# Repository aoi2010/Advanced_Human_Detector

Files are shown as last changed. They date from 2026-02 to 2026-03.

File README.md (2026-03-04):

# Advanced Human Detector
This is a human detector which uses HmmD Mmwave Sensor to detect humans.

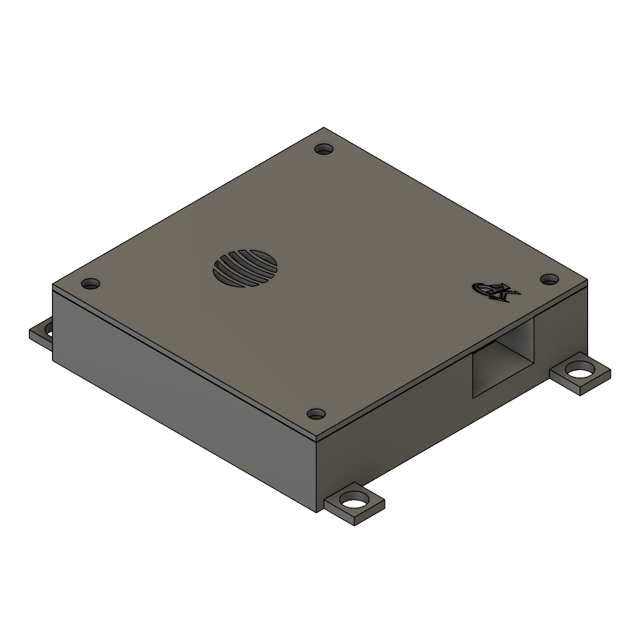
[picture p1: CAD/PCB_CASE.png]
PCB Case


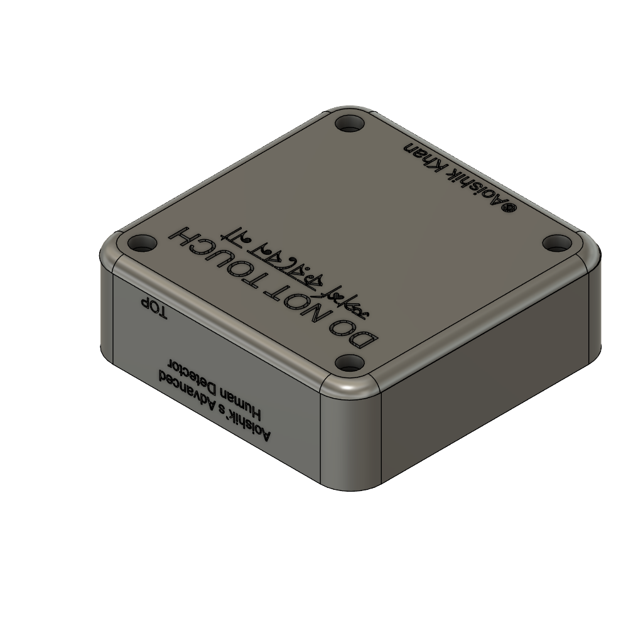
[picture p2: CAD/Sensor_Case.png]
Sensor Case


### Inspiration

I wanted to create a human detector using the Mmwave Sensor to detect humans and alert me when human is detected cuz some people always steals the flowers in my garden, and I want to catch them in the act.

### Challenges

Believe it or not, this was my second time using Fusion 360 and KiCad! I watched numerous tutorials and guides and did a kg of googling, but in the end, I'm pretty proud of the final product. I had the most struggle figuring out how to make sketches, and with the new mouse controls, it definitely took me a while to get the hang of it. Also in KiCad, I had a lot of trouble with footprints and making sure everything was aligned properly and the traces were correct(but it became a litle long traces).

### How To Use This
- STEP 1: Buy all the things listed in the BOM, a 0.1µf decoupling capacitor(ceramic & and not mentioned in BOM) & print the case for the sensor and also order the PCB(PCB/motionalr_mcu.zip).
- STEP 2: Solder the 0.1µf decoupling capacitor to the HMMD mmWave Sensor. One leg of it to VCC and another leg to GND.
- STEP 3: Assemble the PCB.
- STEP 4: Flash MicroPython to the XIAO and place the main.py in the XIAO.
- STEP 5: Connect the PCB to the sensor using a LAN Cable(less than 3m) or any twisted Pair Cable(Use the following table as reference).

| Twisted Pair | Use For |
| --- | --- |
| Pair 1 | 3.3V + GND |
| Pair 2 | TX + GND |
| Pair 3 | RX + GND |
| Pair 4 | OT2 + GND |

- STEP 6: Put the sensor in the case and put it outside or where you want it to be placed.(You may put it near your bedroom so that it alerts you when someone is coming or near your fridge if you have siblings.)
- STEP 7: Put the PCB inside your house while connected to the sensor using a lan cable(length must be less than 3m).
- STEP 8: Power the XIAO using a USB-C Cable.
- STEP 9: Sleep peacefully or If you want to test go near it and see how it screams.
- STEP 10: Do Anything With It.
Thank You! Also Please give a star to this poor fellow if you like the project. Thank You Again!

### Specifications

BOM: 
- 1x [Seeed Studio XIAO ESP32-C3 development board](https://robu.in/product/seeed-studio-xiao-esp32c3-tiny-mcu-board-with-wi-fi-and-ble-battery-charge-supported-power-efficiency-and-rich-interface/)
- 1x [Waveshare HMMD 24 GHz mmWave human presence sensor](https://robu.in/product/waveshare-human-micro-motion-detection-mmwave-sensor-24ghz-mmwave-radar-based-on-s3km1110-adopts-fmcw-technology/)
- 1x [Passive piezo buzzer, 3 V, Ø12 mm](https://robu.in/product/hc12075c-16-cldz-electromagnetic-passive-integrated-buzzer-1-5-3v12x7-5mmimpedance16%CF%89lateralpronunciation/)
- 1x [NPN transistor 2N2222, TO-92 package](https://robu.in/product/2n2222-npn-transistor-pack-of-20/)
- 1x [Resistor 10 kΩ, ¼ W, through-hole](https://robu.in/product/mfr-25frf52-10k-yageo-metal-film-resistors-10k%CF%89-250mw-%C2%B1100ppm-%E2%84%83-%C2%B11-plugind2-4xl6-3mm-through-hole-resistors-rohs/)
- 1x [Resistor 1 kΩ, ¼ W, through-hole](https://robu.in/product/1k-ohm-0-25w-metal-film-resistor-pack-of-100/)
- 1x [Resistor 100–200 Ω, ¼ W, through-hole](https://robu.in/product/0-25w-100-ohm-resistor-pack-of-100/)
- 1x [Resistor 22–33 Ω, through-hole](https://robu.in/product/mf25-33r-multicomp-pro-through-hole-resistor-33-ohm-mf25-series-250-mw-%C2%B1-1-axial-leaded-250-v)
- 1x [Signal diode 1N4148](https://robu.in/product/1n4148-onsemi-100v-1v10ma-4ns-200ma-do-35-switching-diodes-rohs/)
- 2x [0 Ω SMD resistor](https://robu.in/product/1-month-warranty-149/)
- 1x [5-pin connector / header for HMMD sensor - Male](https://robu.in/product/xh-a-2-5mm-5-pin-wafer-male-connector-through-hole-straight/)
- 1x [5-pin connector / header for HMMD sensor - Female](https://robu.in/product/xh-a-aw-2-5mm-5-pin-female-housing-connector-with-300mm-wire28-awg/)
- 1x [LAN / multi-core cable for sensor connection](https://www.amazon.in/Electronic-Spices-Ethernet-Patch-Network/dp/B0D4HYL67Z)
- 4x [M3x16mm Screws](https://onlyscrews.in/products/copy-of-chhd-m3-x-20mm-pack-of-21?variant=48458789257529)
- 4x [M3x4mm Heatset Inserts](https://onlyscrews.in/products/m4-x-4mm-brass-threaded-inserts?variant=49091565650233)
- 1x [PCB](https://www.lioncircuits.com/) 

Others:
- Micropython Firmware
- PCB Gerber File(PCB/motionalr_mcu.zip)
- Case STL files for 3d Printing
- BOM.csv

Schematic            |  PCB         |   Sensor Case (Top)   |   Sensor Case (Bottom)
:-------------------------:|:-------------------------:|:-------------------------:|:-------------------------:|
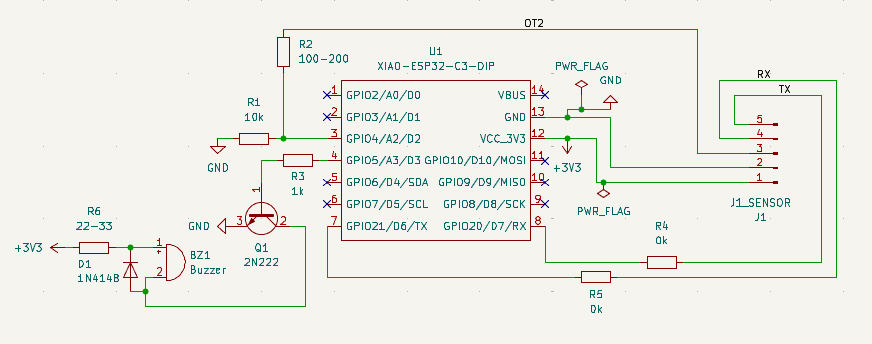
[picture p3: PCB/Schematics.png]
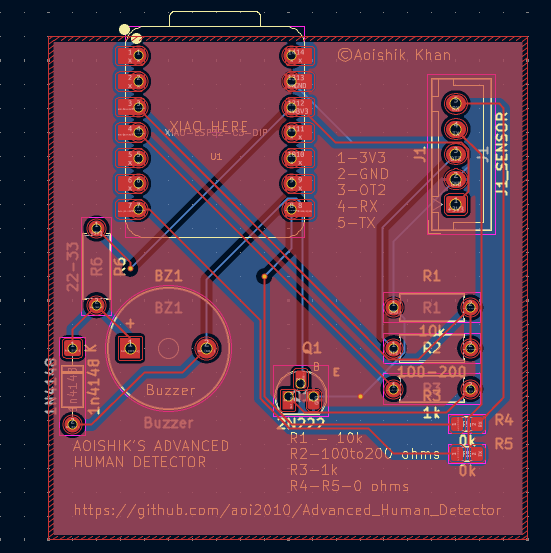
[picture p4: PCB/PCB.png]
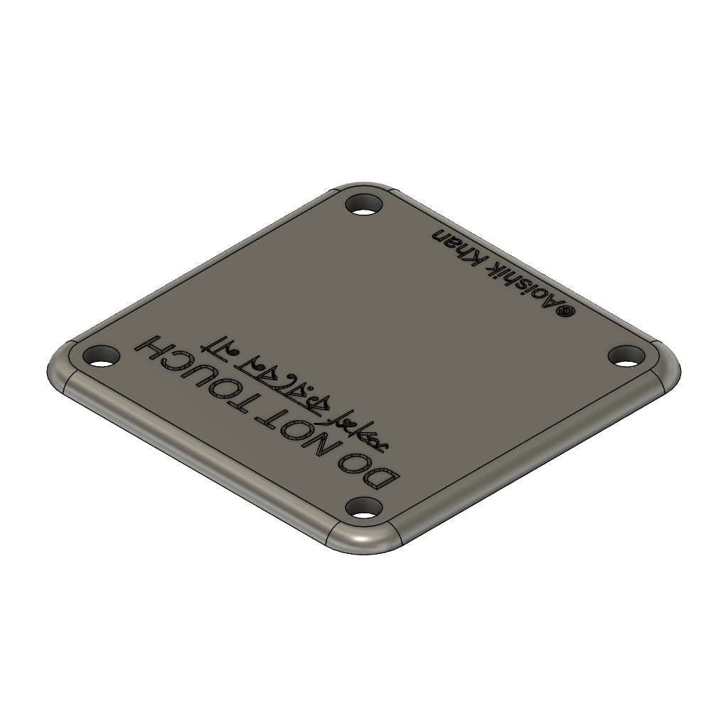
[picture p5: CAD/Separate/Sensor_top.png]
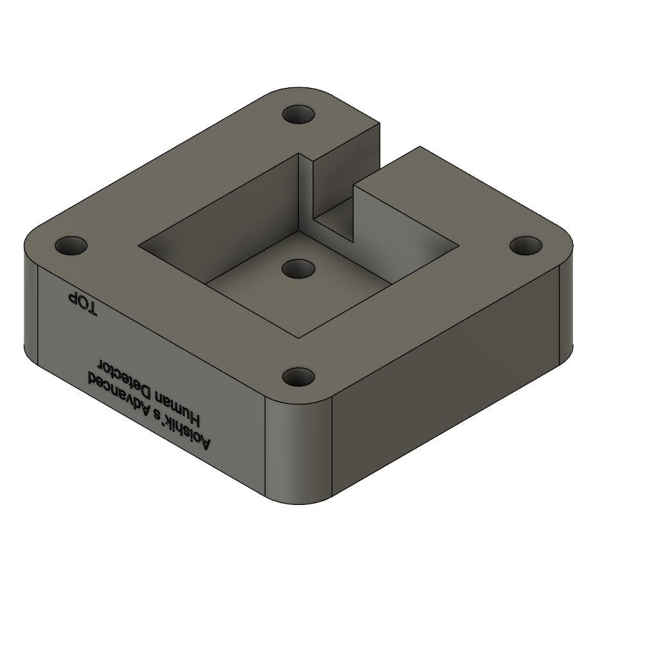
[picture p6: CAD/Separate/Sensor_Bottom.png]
    |    |  | 

PCB Case (Top)            |  PCB Case (Bottom)
:-------------------------:|:-------------------------:
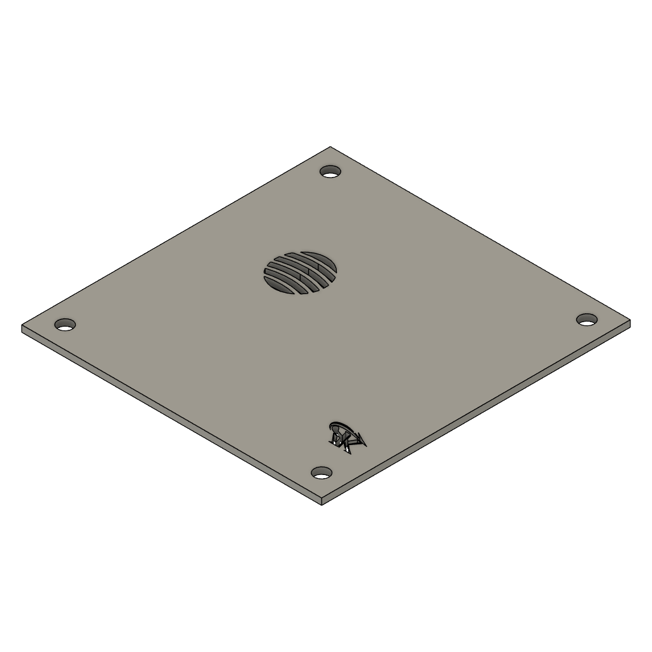
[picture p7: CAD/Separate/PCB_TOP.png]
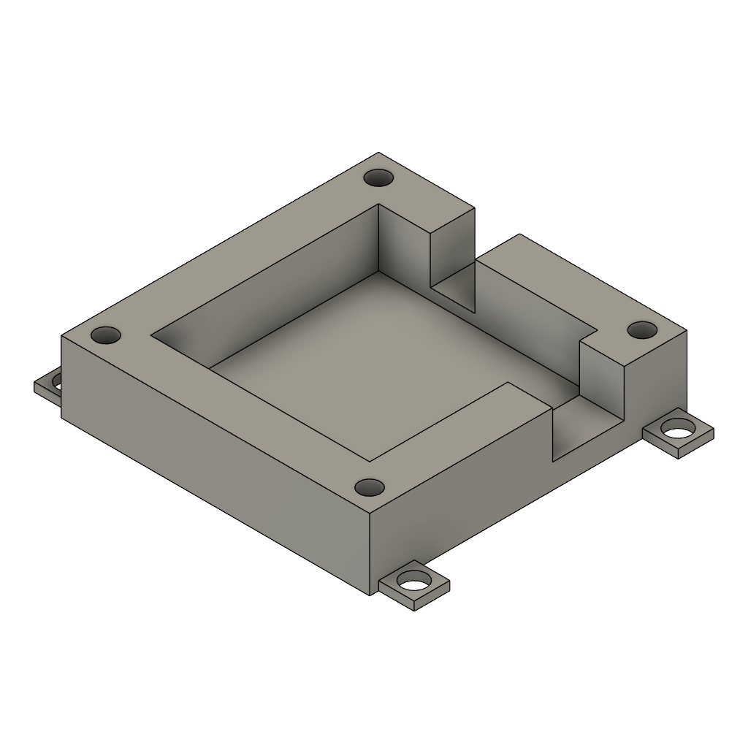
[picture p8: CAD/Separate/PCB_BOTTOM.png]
    |  

### Notes
The code is still basic in functionality because of lack of information on the sensor datasheet, but I will update it as soon as I get the sensor and debug it's output. The case for the mmwave sensor is measured with approx measurement available online, so I will also update the case design once I get the sensor and measure it myself. The PCB will be left bare as I like looking at PCBs.

Edit: I also made the PCB case but after my project was approved. Thank You for understanding.
<div align="center">

## Thanks For Reading! Also leave a star if you like the project! ⭐

</div>

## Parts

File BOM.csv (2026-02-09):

Item | Description | Quantity | Unit Price Approx($) | Unit Price(INR) | Total Price Approx ($) | Total Price(INR) | URL | Product Name in Product Page | Notes
XIAO-ESP32-C3 | Seeed Studio XIAO ESP32-C3 development board | 1 | 5.93 | 534 | 5.93 | 534 | https://robu.in/product/seeed-studio-xiao-esp32c3-tiny-mcu-board-with-wi-fi-and-ble-battery-charge-supported-power-efficiency-and-rich-interface/ | Seeed Studio XIAO ESP32C3 – tiny MCU board with Wi-Fi and BLE
HMMD-mmWave Sensor | HMMD 24 GHz mmWave human presence sensor | 1 | 3.37 | 303 | 3.37 | 303 | https://robu.in/product/waveshare-human-micro-motion-detection-mmwave-sensor-24ghz-mmwave-radar-based-on-s3km1110-adopts-fmcw-technology/ | Waveshare Human Micro-Motion Detection mmWave Sensor, 24GHz mmWave Radar, Based On S3KM1110, Adopts FMCW Technology
BUZZER-PASSIVE | Passive piezo buzzer, 3 V, Ø12 mm | 1 | 0.13 | 12 | 0.13 | 12 | https://robu.in/product/hc12075c-16-cldz-electromagnetic-passive-integrated-buzzer-1-5-3v12x7-5mmimpedance16%CF%89lateralpronunciation/ | HC12075C-16-CLDZ-Electromagnetic passive integrated buzzer-1.5-3V (12×7.5mm) Impedance 16ΩLateral pronunciation
Transistor-2N2222 | NPN transistor 2N2222, TO-92 package | 1 | 0.02 | 2 | 0.02 | 2 | https://robu.in/product/2n2222-npn-transistor-pack-of-20/ | 2N2222 NPN Transistor
Resistor-10K Ω | Resistor 10 kΩ, ¼ W, through-hole | 1 | 0.02 | 1.91 | 0.02 | 1.91 | https://robu.in/product/mfr-25frf52-10k-yageo-metal-film-resistors-10k%CF%89-250mw-%C2%B1100ppm-%E2%84%83-%C2%B11-plugind2-4xl6-3mm-through-hole-resistors-rohs/ | MFR-25FRF52-10K-YAGEO-Metal Film Resistors 10kΩ 250mW ±100ppm/℃ ±1% Plugin,D2.4xL6.3mm Through Hole Resistors ROHS
Resistor-1K Ω | Resistor 1 kΩ, ¼ W, through-hole | 1 | 0.1 | 0.35 | 0.1 | 0.35 | https://robu.in/product/1k-ohm-0-25w-metal-film-resistor-pack-of-100/ | 1k Ohm 0.25W Metal Film Resistor
Resistor-100–200 Ω | Resistor 100–200 Ω, ¼ W, through-hole | 1 | 0.1 | 0.29 | 0.1 | 0.29 | https://robu.in/product/0-25w-100-ohm-resistor-pack-of-100/ | 100 Ohm 0.25W Metal Film Resistor
Resistor-22–33Ω | Resistor 22–33 Ω, through-hole | 1 | 0.02 | 2.08 | 0.02 | 2.08 | https://robu.in/product/mf25-33r-multicomp-pro-through-hole-resistor-33-ohm-mf25-series-250-mw-%C2%B1-1-axial-leaded-250-v | MF25 33R-MULTICOMP PRO-Through Hole Resistor, 33 ohm, MF25 Series, 250 mW, ± 1%, Axial Leaded, 250 V
Diode-1N4148 | Signal diode 1N4148 | 1 | 0.07 | 6 | 0.07 | 6 | https://robu.in/product/1n4148-onsemi-100v-1v10ma-4ns-200ma-do-35-switching-diodes-rohs/ | 1N4148-Onsemi-100V 1V@10mA 4ns 200mA DO-35 Switching Diodes ROHS
Resistor-0R | 0 Ω SMD resistor | 2 | 0.05 | 0.16 | 0.1 | 0.32 | https://robu.in/product/1-month-warranty-149/ | RC0805FR-070RL-YAGEO-0 Ohms Jumper Chip Resistor 0805 (2012 Metric) Moisture Resistant Thick Film
5pin Connector-Male | 5-pin connector / header for HMMD sensor - Male | 1 | 0.01 | 1.26 | 0.01 | 1.26 | https://robu.in/product/xh-a-2-5mm-5-pin-wafer-male-connector-through-hole-straight/ | XH-A-2.5mm-5 pin Wafer Male Connector Through Hole Straight
5pin Connector-Female | 5-pin connector / header for HMMD sensor - Female | 1 | 0.14 | 13 | 0.14 | 13 | https://robu.in/product/xh-a-aw-2-5mm-5-pin-female-housing-connector-with-300mm-wire28-awg/ | XH-A/AW-2.5mm-5 pin Female Housing Connector with 300mm Wire(28 AWG)
LAN CABLE | LAN / multi-core cable for sensor connection | 1 | 1.88 | 169 | 1.88 | 169 | https://www.amazon.in/Electronic-Spices-Ethernet-Patch-Network/dp/B0D4HYL67Z | Electronic Spices RJ45 Cat 6 Cable Ethernet Patch LAN Network Laptop Cable (2 M),2M, Grey
Screws | M3x16mm Screws | 4 | 0.02 | 2.12 | 0.08 | 8.48 | https://onlyscrews.in/products/copy-of-chhd-m3-x-20mm-pack-of-21?variant=48458789257529 | M3 X 16mm Slotted CHHD SS 304 Screw (Dia. 3mm, Length 16mm)
Heat Set Inserts | M3x4mm Heatset Inserts | 4 | 0.03 | 2.6 | 0.12 | 10.4 | https://onlyscrews.in/products/m4-x-4mm-brass-threaded-inserts?variant=49091565650233 | M3 X 4mm Brass Threaded Inserts (Dia. 3mm, Length 4mm)
ONLYSCREWS SHIPPING | Shipping Charges | 1 | 0.67 | 60 | 0.67 | 60 | N/A | N/A
Robu Shipping | Shipping Charges | 1 | 0.54 | 49 | 0.54 | 49 | https://support.robu.in/index.php | N/A | My Order is Not Above Rs. 999
PCB | PCB Fabrication | 5 | 2.15 | 193.2 | 10.73 | 966 | https://www.lioncircuits.com/ | PCB Fabrication - Lion Circuits | Lion Circuits

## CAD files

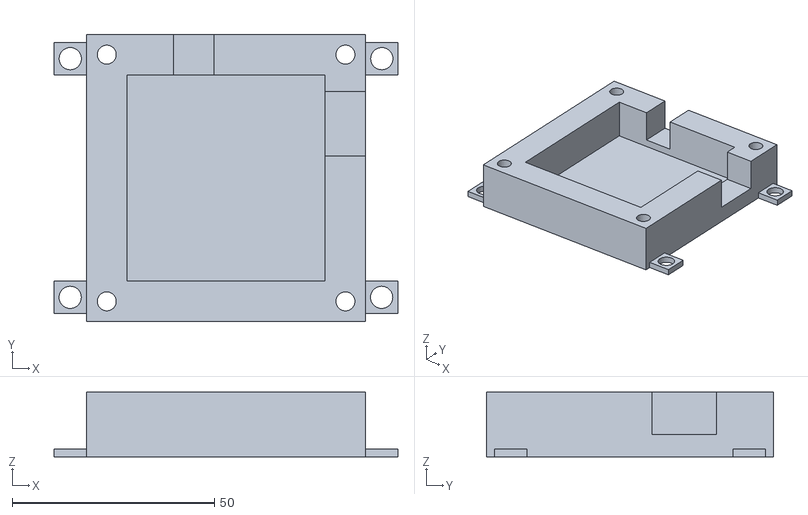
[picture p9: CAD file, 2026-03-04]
CAD/For 3d Printing/PCB_Bottom.stl
85.0 x 71.0 x 16.0

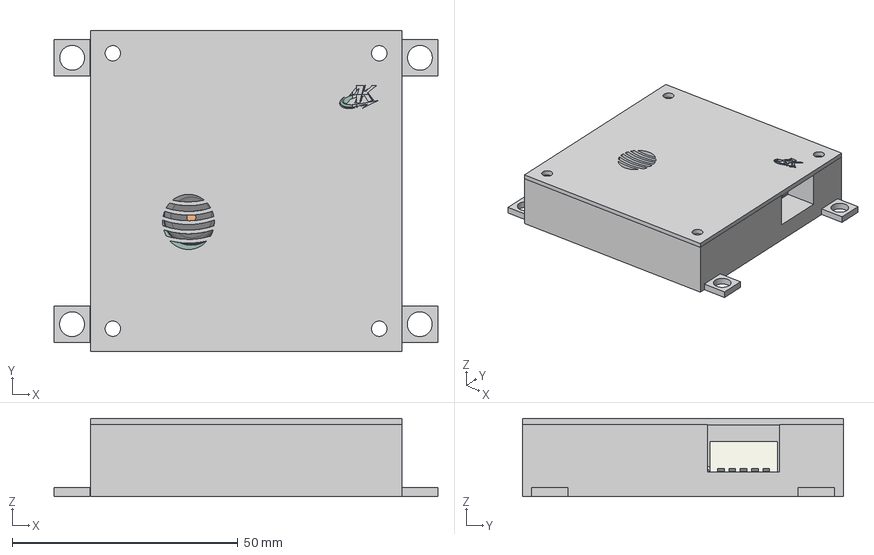
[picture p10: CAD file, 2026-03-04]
CAD/PCB_Case.step
85.0 x 71.0 x 17.4 mm

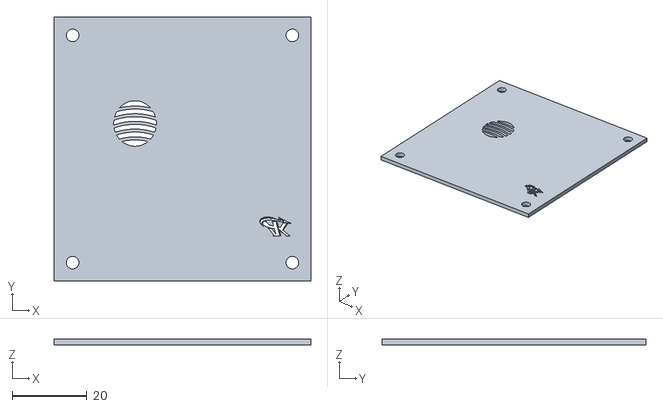
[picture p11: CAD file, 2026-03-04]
CAD/For 3d Printing/PCB_TOP.stl
69.0 x 71.0 x 1.50

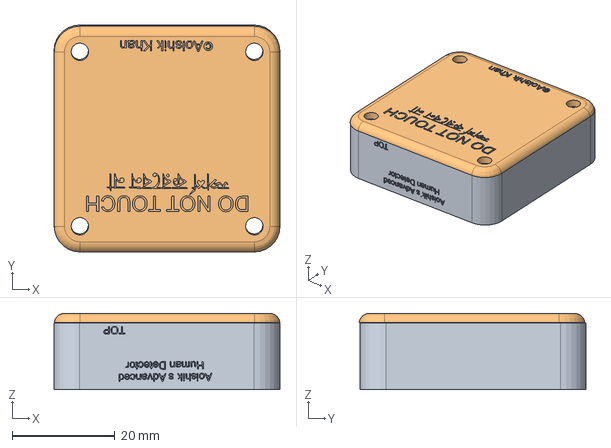
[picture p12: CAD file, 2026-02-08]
CAD/Sensor_Case.step
44.0 x 44.2 x 14.8 mm

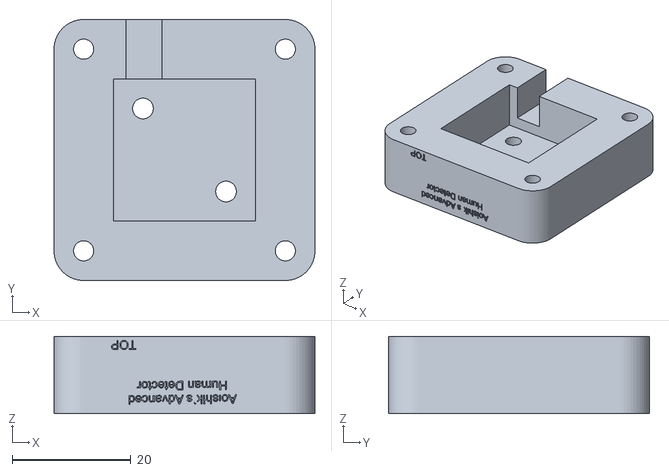
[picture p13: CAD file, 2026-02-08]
CAD/For 3d Printing/Sensor_Bottom.stl
44.0 x 44.0 x 13.0

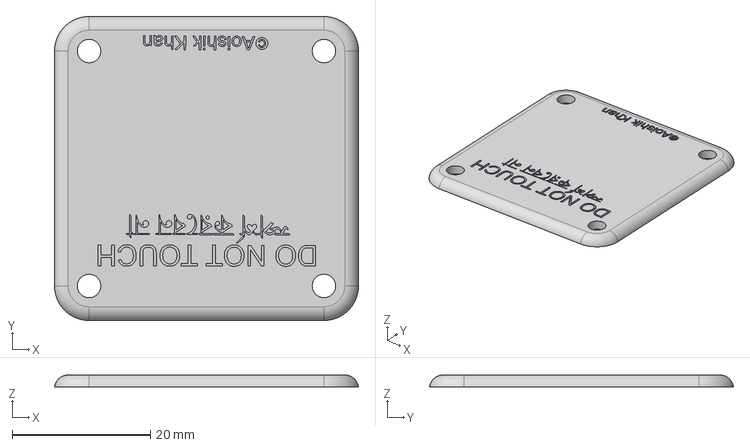
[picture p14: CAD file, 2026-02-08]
CAD/Separate/Sensor_top.step
44.0 x 44.0 x 1.75 mm

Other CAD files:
CAD/Separate/PCB_BOTTOM.step
CAD/Separate/PCB_TOP.step
CAD/For 3d Printing/Sensor_top.stl
CAD/Separate/Sensor_Bottom.step
CAD/PCB_Case.f3z
CAD/Sensor_Case.f3z
CAD/Separate/Sensor_Bottom.f3d
CAD/Separate/Sensor_Top.f3d

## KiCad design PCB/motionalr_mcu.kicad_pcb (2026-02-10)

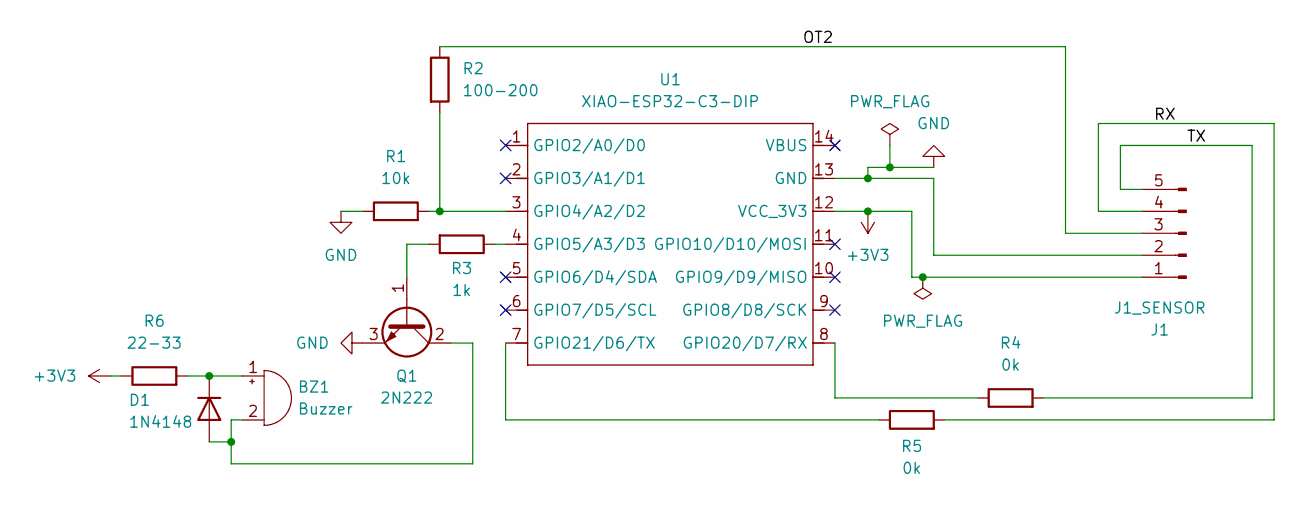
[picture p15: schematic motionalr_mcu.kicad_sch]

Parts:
BZ1: Buzzer; Buzzer_12x9.5RM7.6
D1: 1N4148; D_DO-35_SOD27_P7.62mm_Horizontal
J1: J1_SENSOR; JST_XH_B5B-XH-A_1x05_P2.50mm_Vertical
Q1: 2N222; TO-92_HandSolder
R1: 10k; R_Axial_DIN0207_L6.3mm_D2.5mm_P7.62mm_Horizontal
R2: 100-200; R_Axial_DIN0207_L6.3mm_D2.5mm_P7.62mm_Horizontal
R3: 1k; R_Axial_DIN0207_L6.3mm_D2.5mm_P7.62mm_Horizontal
R4, R5: 0k; R_0805_2012Metric_Pad1.20x1.40mm_HandSolder
R6: 22-33; R_Axial_DIN0207_L6.3mm_D2.5mm_P7.62mm_Horizontal
U1: XIAO-ESP32-C3-DIP; XIAO-ESP32C3-DIP

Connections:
+3V3: J1.1, R6.1, U1.12 (VCC_3V3)
/OT2: J1.3, R2.1
/RX: J1.5, R4.2
/TX: J1.4, R5.2
GND: J1.2, Q1.3 (E), R1.1, U1.13 (GND)
unnamed 5: BZ1.1 (+), D1.1 (K), R6.2; also elsewhere on the board
unnamed 6: BZ1.2 (-), D1.2 (A), Q1.2 (C); also elsewhere on the board
unnamed: Q1.1 (B), R3.2
unnamed: R1.2, R2.2, U1.3 (GPIO4/A2/D2)
unnamed: R3.1, U1.4 (GPIO5/A3/D3)
unnamed: R4.1, U1.8 (GPIO20/D7/RX)
unnamed: R5.1, U1.7 (GPIO21/D6/TX)

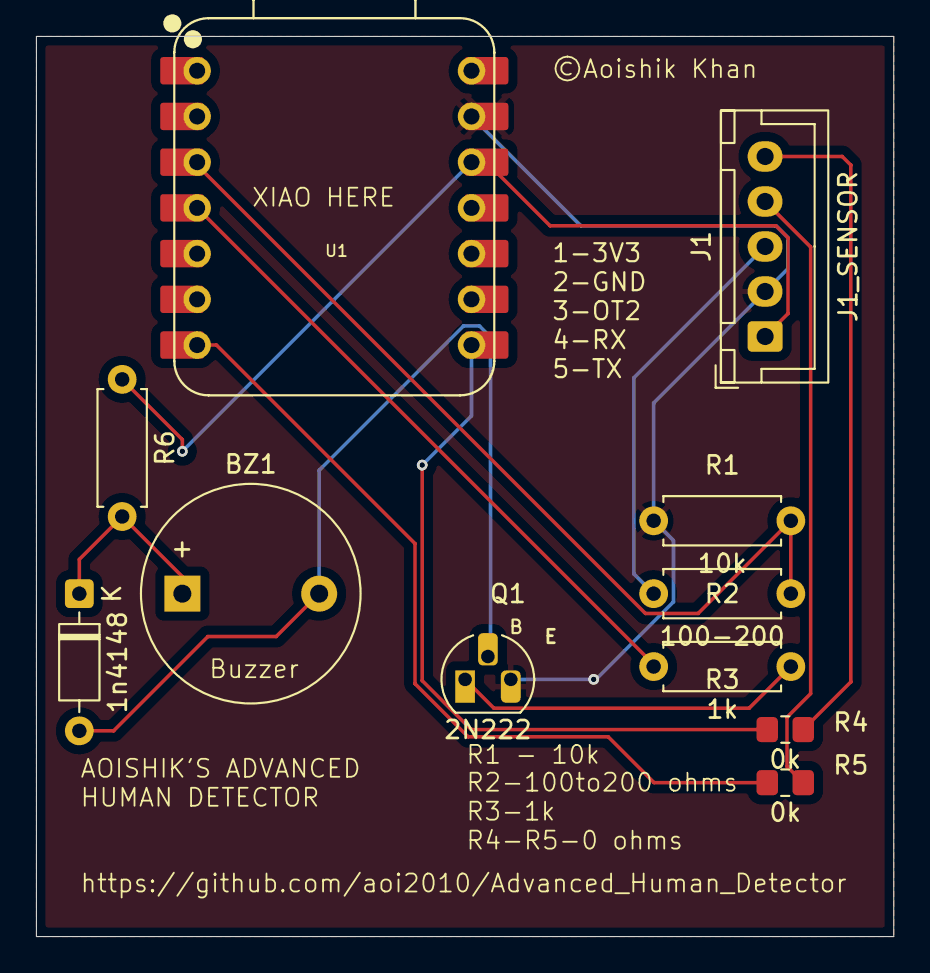
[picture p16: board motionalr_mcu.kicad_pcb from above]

Board: 2 copper layers, 47.6 x 50.0 mm, 11 parts (0 on the bottom side), 12 nets.

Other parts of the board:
1n4148: 1N4148; D_DO-35_SOD27_P7.62mm_Horizontal

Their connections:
unnamed 5: 1n4148.1 (K); also elsewhere on the board
unnamed 6: 1n4148.2 (A); also elsewhere on the board

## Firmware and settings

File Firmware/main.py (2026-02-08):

# This code is for Advanced Human Detector - https://github.com/aoi2010/Advanced_Human_Detector
# MicroPython Code
from machine import Pin, PWM
import time

# =========================
# CONFIGURATION
# =========================

OT2_PIN = 4          # HMMD detection output
BUZZER_PIN = 5       # Passive buzzer (PWM)
BUZZER_FREQ = 2000   # Hz (audible, not harsh)
BUZZER_DUTY = 512    # 50% duty (0–1023)

# Detection filtering
DETECT_CONFIRM_MS = 150    # must stay HIGH for this time
RELEASE_CONFIRM_MS = 300   # must stay LOW for this time
LOOP_DELAY_MS = 20         # main loop delay

# =========================
# HARDWARE SETUP
# =========================

ot2 = Pin(OT2_PIN, Pin.IN)
buzzer = PWM(Pin(BUZZER_PIN))
buzzer.duty(0)              # buzzer OFF at boot
buzzer.freq(BUZZER_FREQ)

# =========================
# STATE VARIABLES
# =========================

last_state = 0              # last stable OT2 state
state_change_time = time.ticks_ms()
buzzer_on = False

# =========================
# HELPER FUNCTIONS
# =========================

def buzzer_enable():
    global buzzer_on
    if not buzzer_on:
        buzzer.duty(BUZZER_DUTY)
        buzzer_on = True

def buzzer_disable():
    global buzzer_on
    if buzzer_on:
        buzzer.duty(0)
        buzzer_on = False

# =========================
# MAIN LOOP
# =========================

while True:
    now = time.ticks_ms()
    current = ot2.value()

    # Detect state change
    if current != last_state:
        state_change_time = now
        last_state = current

    # Confirm detection
    if current == 1:
        if time.ticks_diff(now, state_change_time) >= DETECT_CONFIRM_MS:
            buzzer_enable()
    else:
        if time.ticks_diff(now, state_change_time) >= RELEASE_CONFIRM_MS:
            buzzer_disable()

    time.sleep_ms(LOOP_DELAY_MS)

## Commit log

2026-02-08 Add sensor CAD models and PCB designs
    Add 3D assets and PCB project for the sensor hardware: 3D-printable STL files (Sensor_top/Bottom), STEP and PNG CAD files for the full case and separated parts, and KiCad PCB project files (motionalr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
    [Sensor_Bottom.step, Sensor_Bottom.stl, Sensor_Case.step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]
2026-02-08 Add Advanced Human Detector MicroPython firmware
    Add Firmware/main.py implementing MicroPython firmware for the Advanced Human Detector project. The script configures an OT2 sensor input and a PWM-driven passive buzzer, includes debounce/confirmation timing (DETECT_CONFIRM_MS, RELEASE_CONFIRM_MS) and a main loop that enables/disables the buzzer based on stable sensor state.
    [main.py]
2026-02-08 Add PCB layout and schematics images
    Add two new image assets to the PCB folder: PCB/PCB.png (board layout) and PCB/Schematics.png (circuit schematics). These images provide PCB artwork and schematic diagrams for documentation, review, 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
2026-02-09 Add BOM.csv and expand README with project details
    Add a new BOM.csv listing parts, quantities, prices and supplier links. Expand README.md with a project overview, inspiration, challenges, specifications, full BOM summary, asset references (schemati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
    [BOM.csv]
2026-02-09 Revise BOM formatting in README.md
    Updated the bill of materials (BOM) section in the README.md to reflect changes in formatting.
2026-02-09 Add links to BOM items in README
    Replace the plain BOM component list with Markdown links to vendor/product pages for each item to make sourcing easier (e.g., Seeed XIAO, Waveshare HMMD, buzzer, resistors, connectors, cables, screws, heatset inserts, PCB). Also fix minor typos in the component names. Only README.md was modified; no functional changes.
2026-02-09 Fix image filename casing in README
    Corrected the filename casing for the bottom sensor case image in the README.
2026-02-09 Fix image filename for sensor case in README
    Corrected the filename for the top sensor case image in the README.
2026-02-10 Changed a typo in schematics
    [motionalr_mcu.kicad_pcb, motionalr_mcu.kicad_sch]
2026-02-18 Add usage instructions to README
    Added a step-by-step guide for using the sensor project, including assembly and connection instructions.
2026-02-20 Add sensor case CAD files
    Add CAD assets for the sensor enclosure: a full case (.f3z) and separate top/bottom models (.f3d). .
    [Sensor_Bottom.f3d, Sensor_Case.f3z, Sensor_Top.f3d]
2026-03-04 Add PCB case CAD and 3D printing files
    Add CAD assets for the PCB case and printable models: assembled PCB_Case STEP and Autocad (.f3z), preview PNG (CAD/PCB_CASE.png), separate top/bottom STEP and PNG under CAD/Separate, and STL files fo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
    [PCB_BOTTOM.step, PCB_Bottom.stl, PCB_Case.f3z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]

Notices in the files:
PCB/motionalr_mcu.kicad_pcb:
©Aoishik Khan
